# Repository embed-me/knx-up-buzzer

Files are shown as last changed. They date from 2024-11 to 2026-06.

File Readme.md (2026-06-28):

# 🎵 KNX UP-Buzzer Project



The **UP-Buzzer** is a custom KNX-compatible buzzer project designed to fill the gap in the market for simple and functional KNX buzzers. By combining existing open-source hardware with custom components, this project ensures flexibility, ease of use, and extensibility.

## 🚀 Overview

This project integrates:
- 🖨️ Custom PCB
- 🛠️ Firmware
- 🏠 3D-printable housing
- 🧰 Software configuration file

Together, these components enable a KNX-compatible buzzer with additional (untested!) features.

## PCB

The PCB combines available KNX hardware with custom components for the buzzer functionality. Below is an overview of the key parts:

### **BCU (Bus Coupling Unit)**

The BCU interfaces with the KNX bus using the **NCN5130** chip. This project uses the open-source [NanoBCU](https://github.com/OpenKNX/OpenKNX/wiki/NanoBCU) to simplify development.

> 🛒 You can purchase the NanoBCU hardware here: [NanoBCU Standard](https://muster.ing-dom.de/Busankoppler/NanoBCU-Standard.html).

### **MCU (Microcontroller Unit)**

The microcontroller is based on the **RP2040**, an open-source solution provided by [OpenKNX-UP1](https://github.com/OpenKNX/OpenKNX/wiki/OpenKNX-UP1).
To program the board, use the [UP1-Progger](https://github.com/OpenKNX/OpenKNX/wiki/UP1-Progger).

> 🛒 Both the UP1 controller and programmer are available [here](https://muster.ing-dom.de/OpenKNX-UP1/OpenKNX-UP1-Controller2040.html).

### **Buzzer, Proximity Sensor, and Binary Inputs**

The schematic includes:
- A **buzzer** for alert functionality.
- Support for a **proximity sensor** for advanced triggering.
- **Binary inputs** for potential-free connections.

These additional features are currently untested but are included for enthusiasts to explore.

> 🛒 I ordered mine at [JLCPCB](https://jlcpcb.com/).

📂 For schematics, PCB layouts, and Gerber files, see the [hardware documentation](hardware/Readme.md).

## Housing

The housing is designed to fit into a standard flush-mounted box and can be 3D-printed.

📂 Get the 3D model and instructions in the [housing documentation](housing/Readme.md).

## Firmware

The custom firmware is built to be:
- 🔧 Extensible
- ✅ Understandable
- 🔓 Easy to modify

⚠️ Note: Unit tests are not included (yet!), but the code is designed with maintainability in mind.

📂 For build instructions, see the [firmware documentation](firmware/Readme.md).

## 🛠️ Software

The project includes a KNX **product database** for configuration within **ETS**. This allows you to set up and use the device as seamlessly as you would with any commercial product.

📂 Learn how to modify and deploy the product database in the [software documentation](software/Readme.md).

## 📜 License

This project is licensed under **MIT License**. For details, check out the [LICENSE file](LICENSE).

---

Enjoy building and using the **UP-Buzzer**! 🎉

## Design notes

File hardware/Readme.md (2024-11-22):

# Hardware

PCB to add capabilities for buzzing, proximity sensor and binary inputs. The project is based on Altium Designer and can be found in [project](project/)

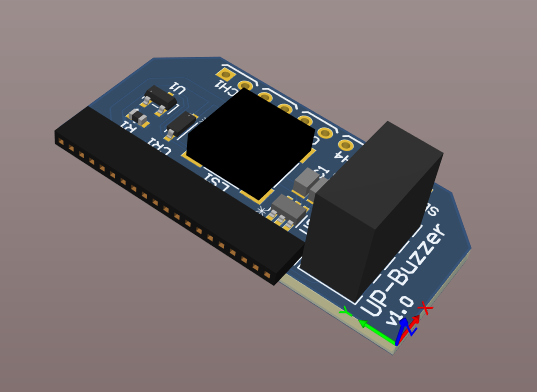
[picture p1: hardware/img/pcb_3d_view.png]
3d


## 3D rendering

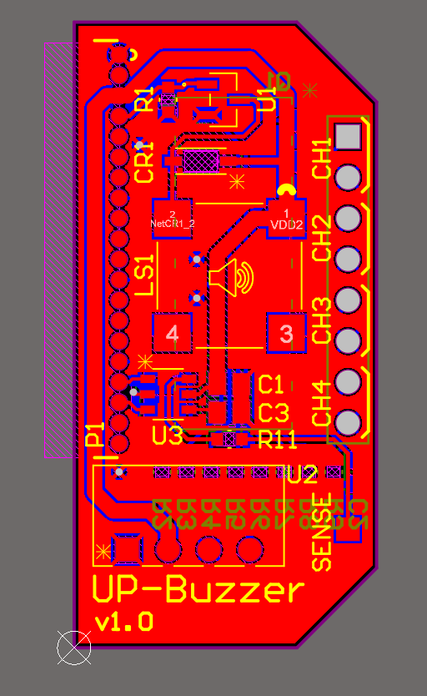
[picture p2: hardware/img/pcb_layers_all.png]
layers

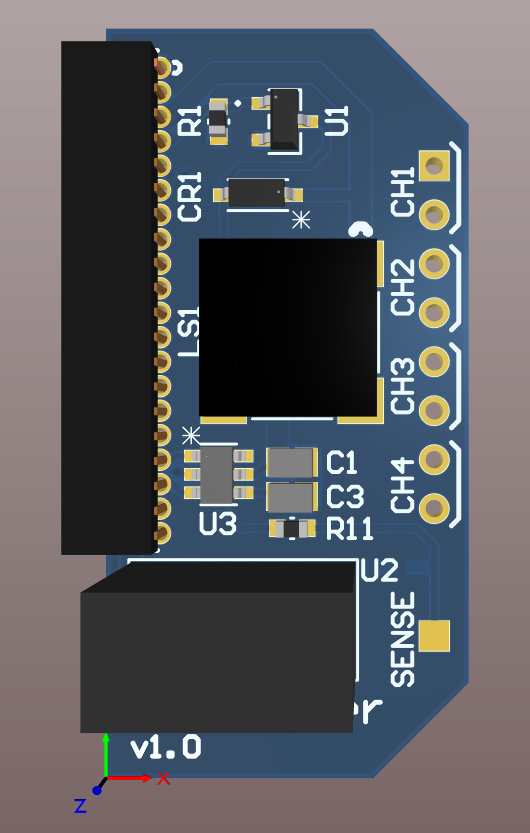
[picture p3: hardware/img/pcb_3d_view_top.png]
top


## Production Package

In case you just want to order the PCB, feel free to use the files in the [production package](production_package/).

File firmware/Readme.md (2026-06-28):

# 🛠️ UP Buzzer - Firmware

To ensure the application functions correctly, the product database must be imported into **ETS**, the physical address must be set, and the application must be written to the device.

## Setup

```bash
pip install platformio
```

## Build

```bash
pio run -e release
```

## Unit Tests

```bash
pio test -e test
```

## Static Code Analysis

```bash
sudo apt-get install -y cppcheck
pio check -e check
```

## Flashing

The **RP2040 UF2 ROM bootloader** is the recommended method for flashing the firmware due to its simplicity.

### Flashing Steps

1. Connect the board to your computer using the debugger port.
2. Press and hold the `Bootsel` button while pressing and releasing the `Reset` button.
3. A new USB drive will appear on your computer.
4. Drag and drop the file `.pio/build/release/firmware.uf2` onto the USB drive.

## Debugging

The easiest way to debug the firmware without using a dedicated debugger is through **printf debugging** via a serial console. 

### Enabling Serial Debugging

By default, logging output is disabled. To enable it:
1. Modify the logger initialization in `main.cpp` by setting the desired log level and ensuring logging starts when the serial connection is established:
   ```cpp
   logger->init(drivers::logger::LOGLEVEL::LOGLEVEL_TRACE, true);
   ```
2. Connect the debugger board to your computer.
3. Open PlatformIO's Serial Monitor.
4. Set the serial settings to 115200 baud rate, 1 stop bit, 8 data bits, no parity.
5. Observe the logging output for debugging information, including early boot messages.

## Extending functionality

The software configurations are organized into **modes**, which can be found in the [modes](src/drivers/knx/data/modes/) directory. During initialization, these modes are populated by reading the memory configuration from flash and are referenced within `MelodyConfig.hpp` via the `KnxConfig.hpp` file.

Once the configuration is loaded, it is applied to the corresponding **behavior**—defined in the [behaviours](src/application/behaviour/) directory—which determines the specific behavior for each mode. The correct behavior is automatically selected by the controller based on the user’s configuration in **ETS**.

To implement a new behavior, it must be added to the existing set of behaviors. It’s recommended to start by copying and modifying an existing mode to create your new behavior.

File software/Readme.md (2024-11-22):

# 🛠️ Software

The UP-Buzzer project integrates seamlessly with **ETS**, primarily tested with **ETS 6.6**. However, the project can be adapted to work with older ETS versions if required.

## Usage

If you do not want to modify the product database and the ETS version matches, it is recommended to simply load the [existing product database](productdatabase/) into ETS.
Once loaded it can be used as you would use any other vendor product.

The melody definitions are based on [RTTTL](https://en.wikipedia.org/wiki/Ring_Tone_Text_Transfer_Language).

Currently, there are up to 8 melodies available, and each can be configured with one of three modes, as described below.

**Note**: Currently, no priority system is implemented, meaning that one melody can interrupt another while it's playing. However, adding a priority strategy is simple and can be done by extending the application.

---

### Trigger

This is the simplest mode. When a trigger telegram with a value of `1` is received, the melody will play once. If the trigger telegram has a value of `0`, it will be ignored, and no action will be taken.

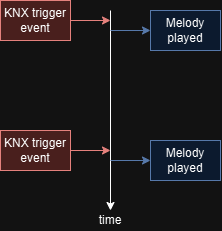
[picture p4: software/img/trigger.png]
Trigger Diagram


**Configuration**

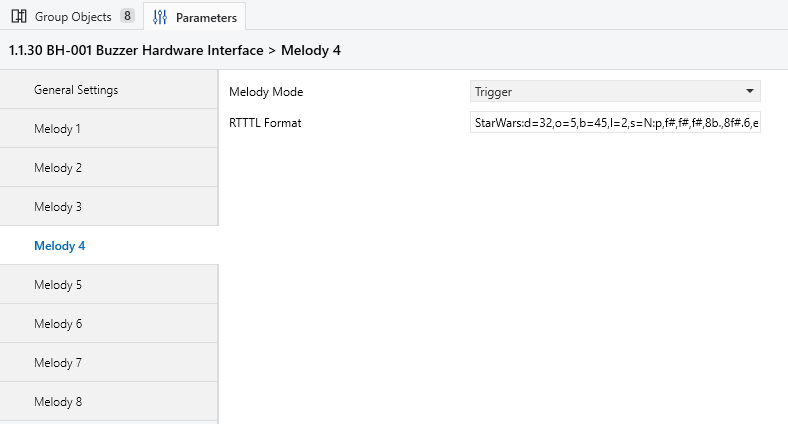
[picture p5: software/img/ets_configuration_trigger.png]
Trigger


---

### Switch

In this mode, when the Group Object receives a "start" command, the melody will play continuously. The melody will keep playing until a "stop" command is received, at which point it will stop.

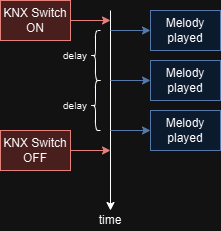
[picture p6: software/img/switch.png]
Switch Diagram


**Configuration**

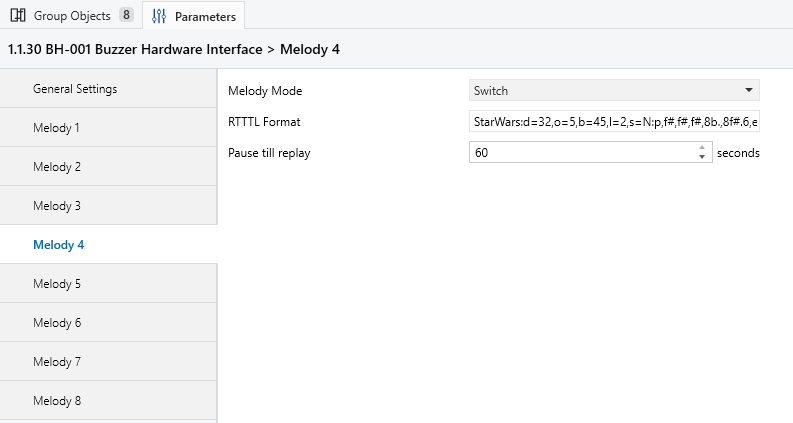
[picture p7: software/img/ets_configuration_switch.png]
Switch


---

### Venting Monitor

This mode allows you to set an upper and lower temperature threshold. The venting monitor is **disabled** when the temperature is within this range, helping to avoid unnecessary alerts.

This feature is particularly useful in scenarios like extreme summer heat or winter conditions when ventilation may not be exceeded. 

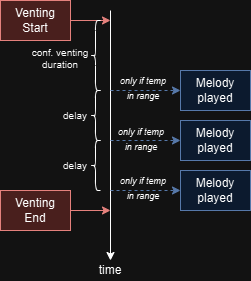
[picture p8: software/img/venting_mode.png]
Venting Monitor Diagram


**Configuration Requirements**:
- Connect the external temperature sensor Group Object.
- Connect the window/door contact sensor Group Object.

Once the window is opened, the ventilation timer starts. If the window remains open, the ventilation timer will restart automatically once the timeout is reached. This process ensures that even if the outdoor temperature drops outside the defined range at a later point in time, the alert will still trigger. Until the window is closed or the temperature thresholds are back in range, the melody will be played.

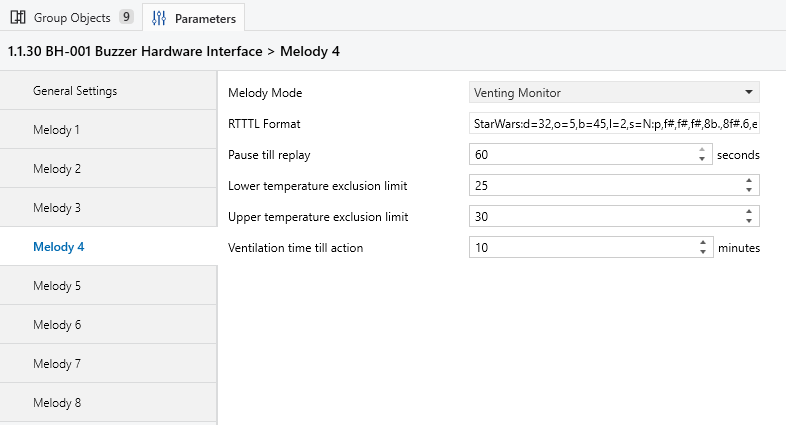
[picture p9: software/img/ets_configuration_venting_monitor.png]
Venting Monitor


## Tools

To create the KNX product database and provide full flexibility, this project uses:

- **[Kaenx-Creator](https://github.com/OpenKNX/Kaenx-Creator)**: A versatile tool for generating KNX product databases.

### Recommended Version

Kaenx-Creator is under active development, and updates can sometimes introduce breaking changes. For this project, it is recommended to use **[v1.8.4](https://github.com/OpenKNX/Kaenx-Creator/tree/v1.8.4)** to ensure compatibility.

- **Binary Download**: [Kaenx Creator v1.8.4](https://github.com/OpenKNX/Kaenx-Creator/releases/download/v1.8.4/Kaenx.Creator.Binaries.zip)
- **MD5 Hash**: `9aeb971f7844eeafb54341031f3e4ef8`

## Generation

To modify or recreate the product database:

1. Open the file `up-buzzer.ae-manu`.
2. Make any necessary changes and increase the version number.
3. Re-deploy the database.

The generated outputs include:

- **`knxprod.h`**: Move this file to [firmware/src/drivers/knx/data/](firmware/src/drivers/knx/data/).

### Note

During re-deployment, the program may become temporarily unresponsive. Allow it some time, as it will eventually complete successfully.

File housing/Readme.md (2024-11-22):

# 🏠 Housing

The housing for the UP-Buzzer is designed to be robust and compact, making it suitable for standard installations.

## Overview

The housing is designed to fit the necessary PCBs securely. Below is an image of the PCB arrangement:

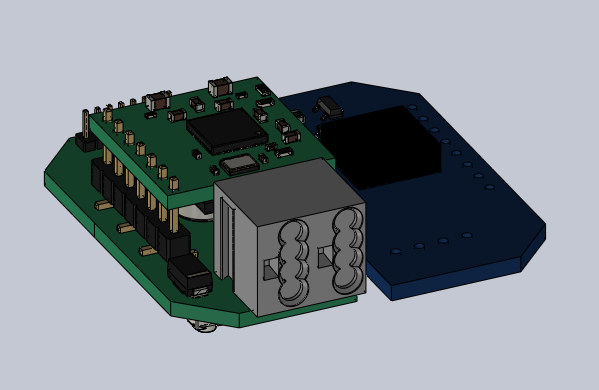
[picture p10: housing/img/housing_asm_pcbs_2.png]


## Model

The housing consists of two parts:
- **Top Shell**
- **Main Housing**

You can find the 3D model files in the [parts](parts/) directory. The assembly combining all PCBs is available in the [assembly](assembly/) directory.

Here’s a rendering of the 3D model with a transparent top shell:

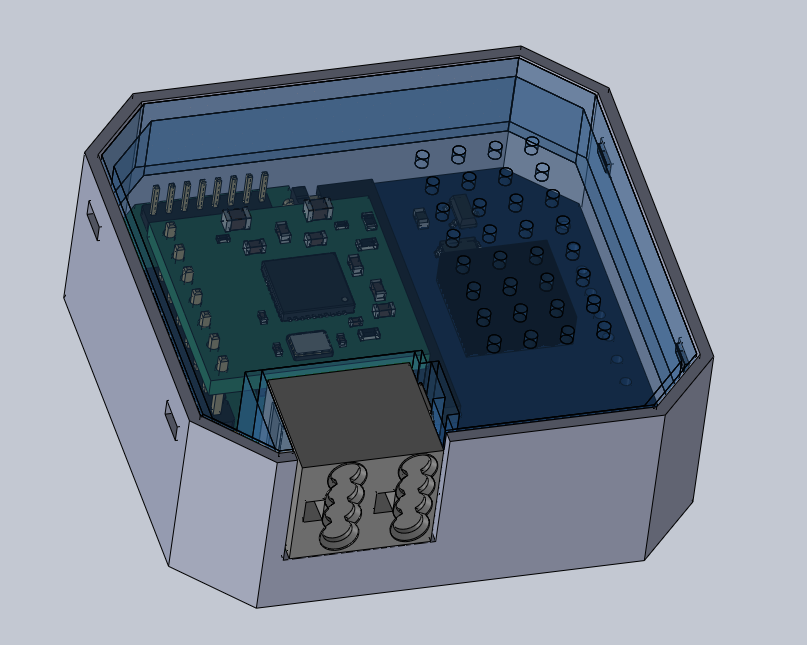
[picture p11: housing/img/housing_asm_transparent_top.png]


## Exported STL Files for Printing

If you’d like to print the housing as-is, the ready-to-use STL files are available in the [print_package](print_package/) directory.

## Result

Below is the final printed result:

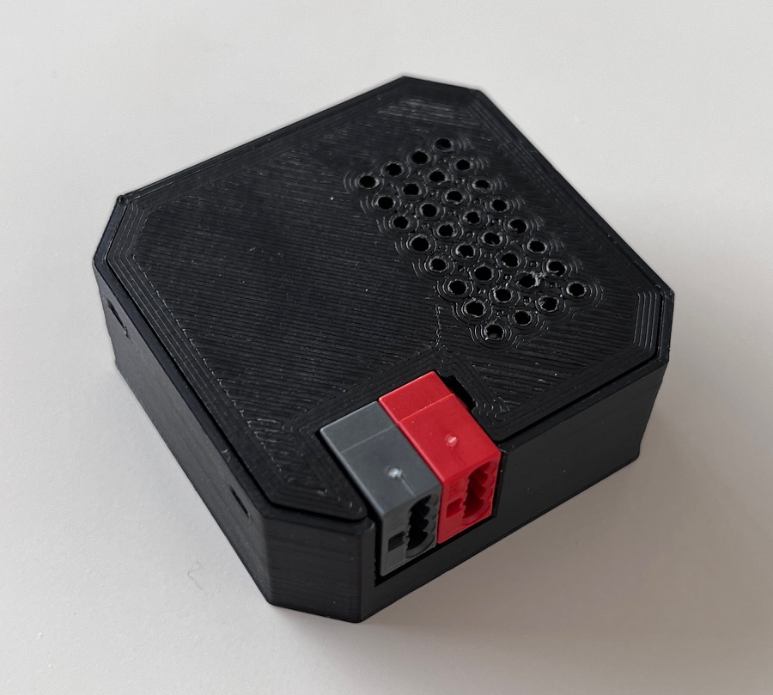
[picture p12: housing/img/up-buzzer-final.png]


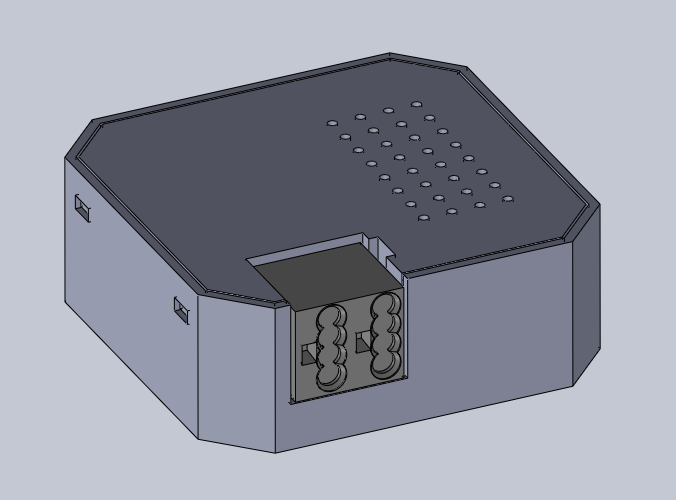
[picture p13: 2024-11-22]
housing/img/housing_asm_enclosed_top.png

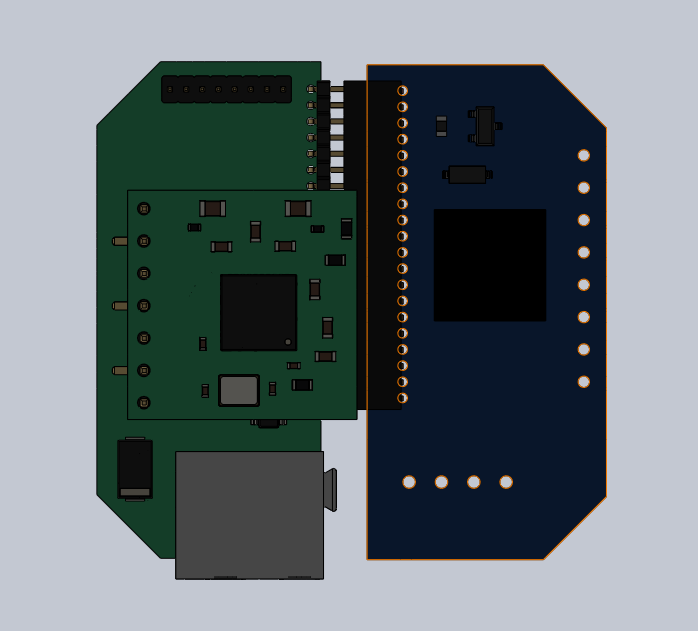
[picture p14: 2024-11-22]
housing/img/housing_asm_pcbs.png

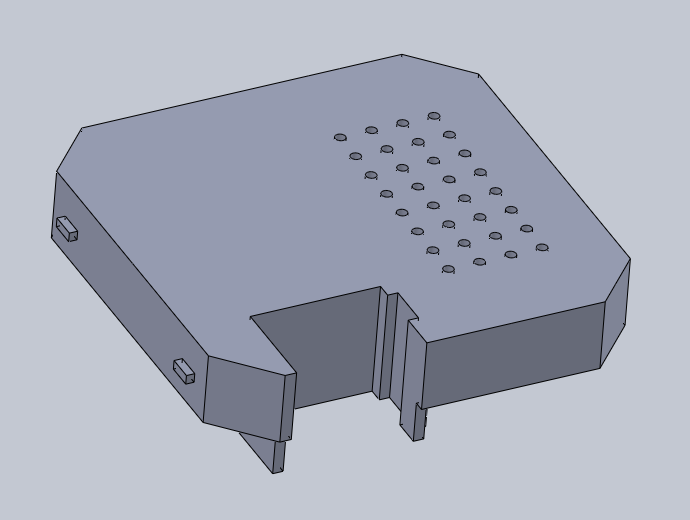
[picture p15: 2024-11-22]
housing/img/housing_top.png

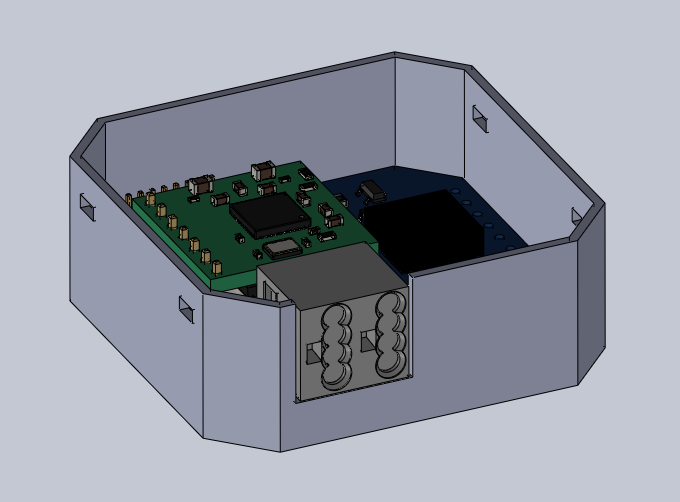
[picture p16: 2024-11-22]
housing/img/housing_asm_removed_top.png

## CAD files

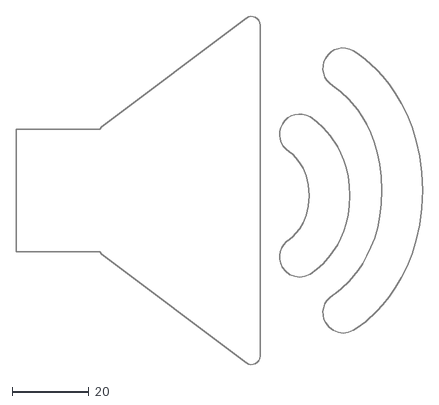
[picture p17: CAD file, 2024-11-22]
hardware/Logo/audio-buzzer.dxf
105.8 x 90.7

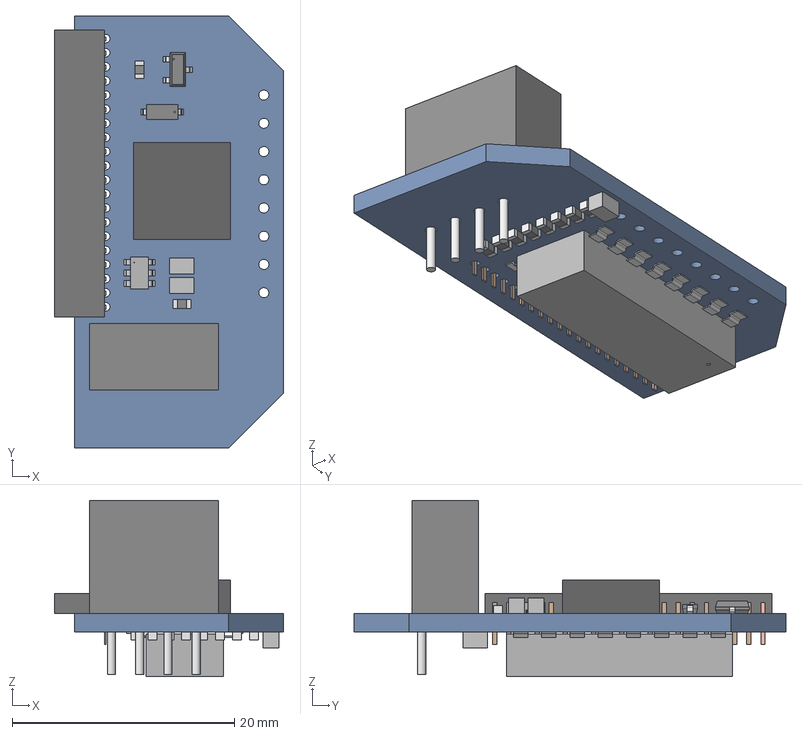
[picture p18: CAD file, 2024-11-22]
hardware/project/UP-Buzzer-PCB.step
20.6 x 38.9 x 15.8 mm
Extruded x 4
pinheader_20pin_127mm_pitch
SOD123_DIO

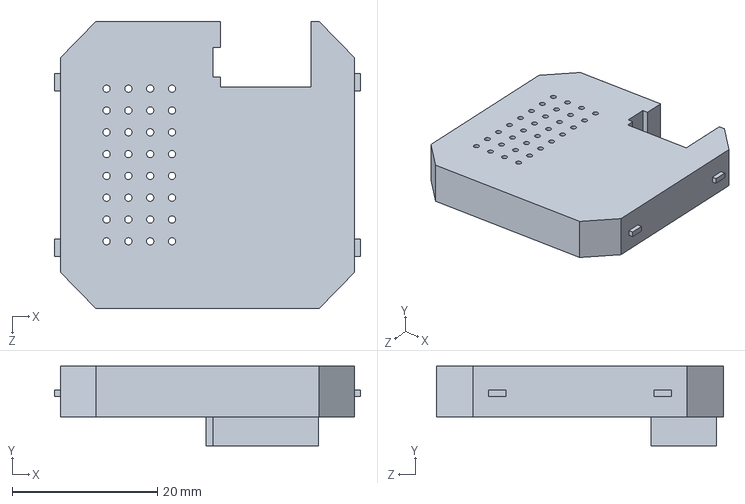
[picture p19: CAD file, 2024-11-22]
housing/parts/UP-Buzzer-housing-upper.SLDPRT
42.1 x 11.0 x 39.5 mm

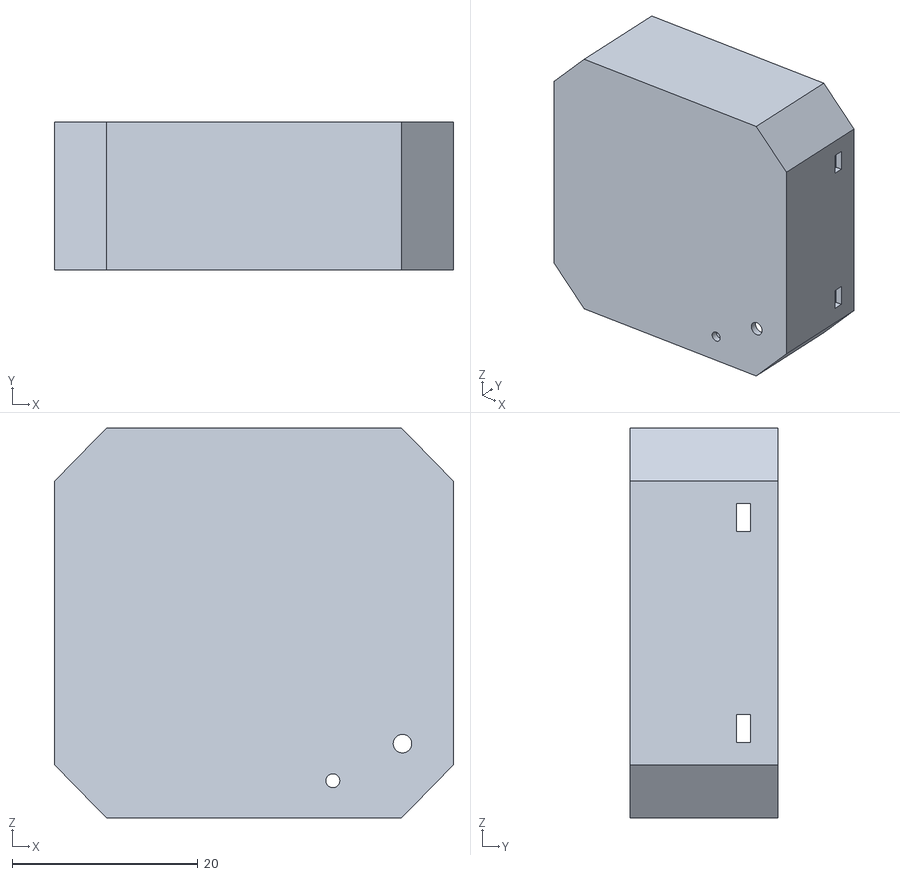
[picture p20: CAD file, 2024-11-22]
housing/print_package/UP-Buzzer-housing.STL
43.0 x 16.0 x 42.0

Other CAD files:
housing/parts/UP-Buzzer-housing.SLDPRT
housing/print_package/UP-Buzzer-housing-upper.STL

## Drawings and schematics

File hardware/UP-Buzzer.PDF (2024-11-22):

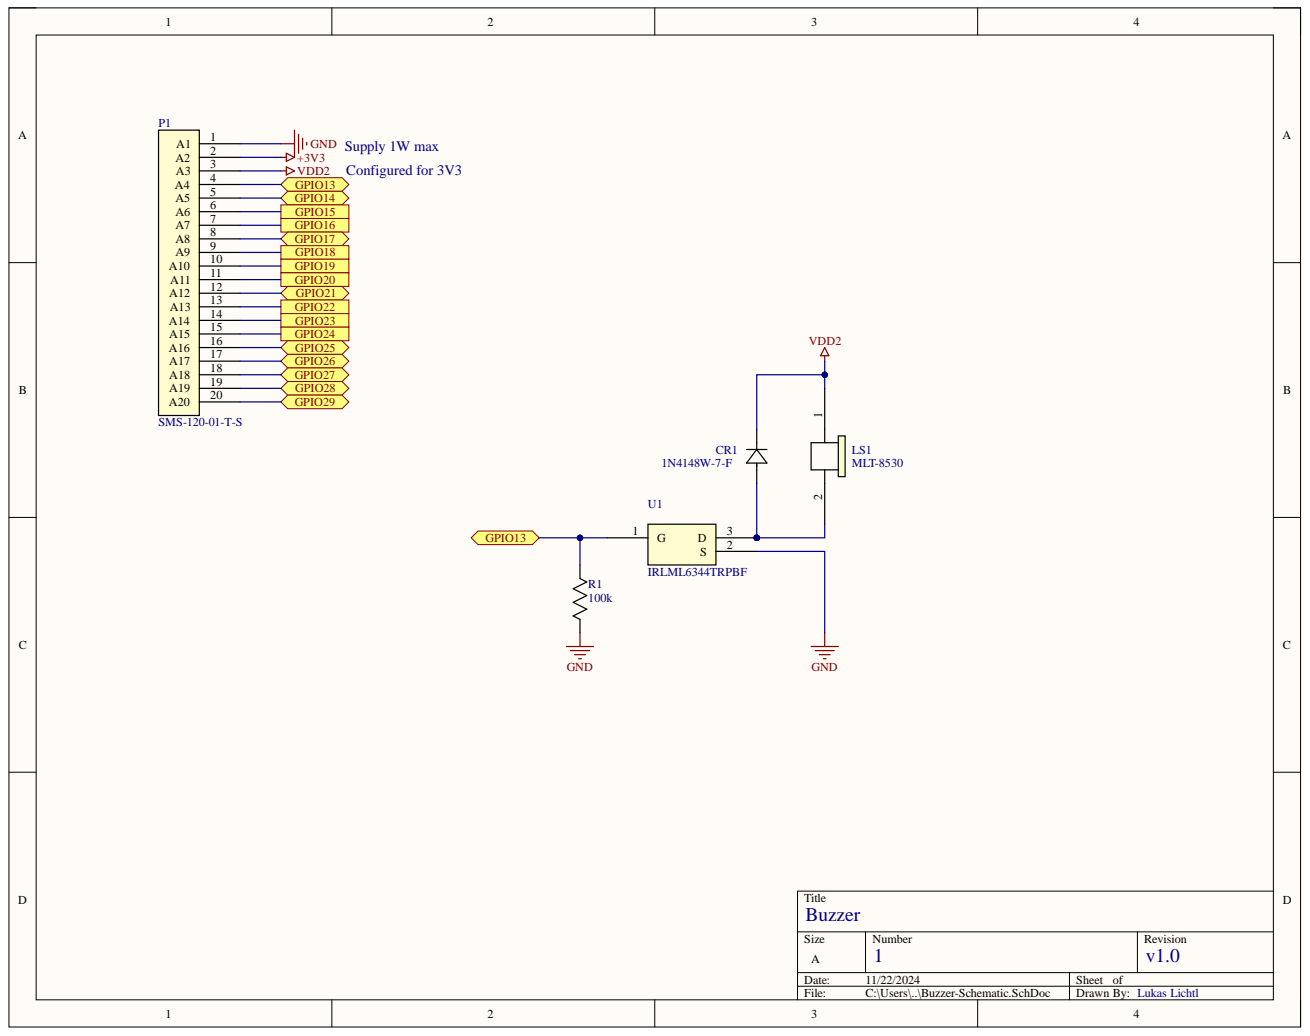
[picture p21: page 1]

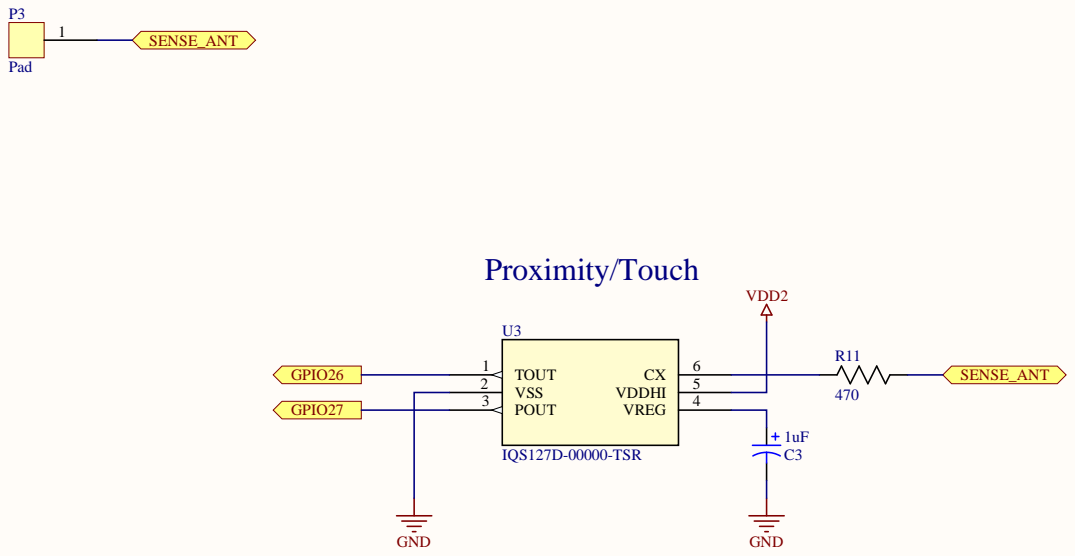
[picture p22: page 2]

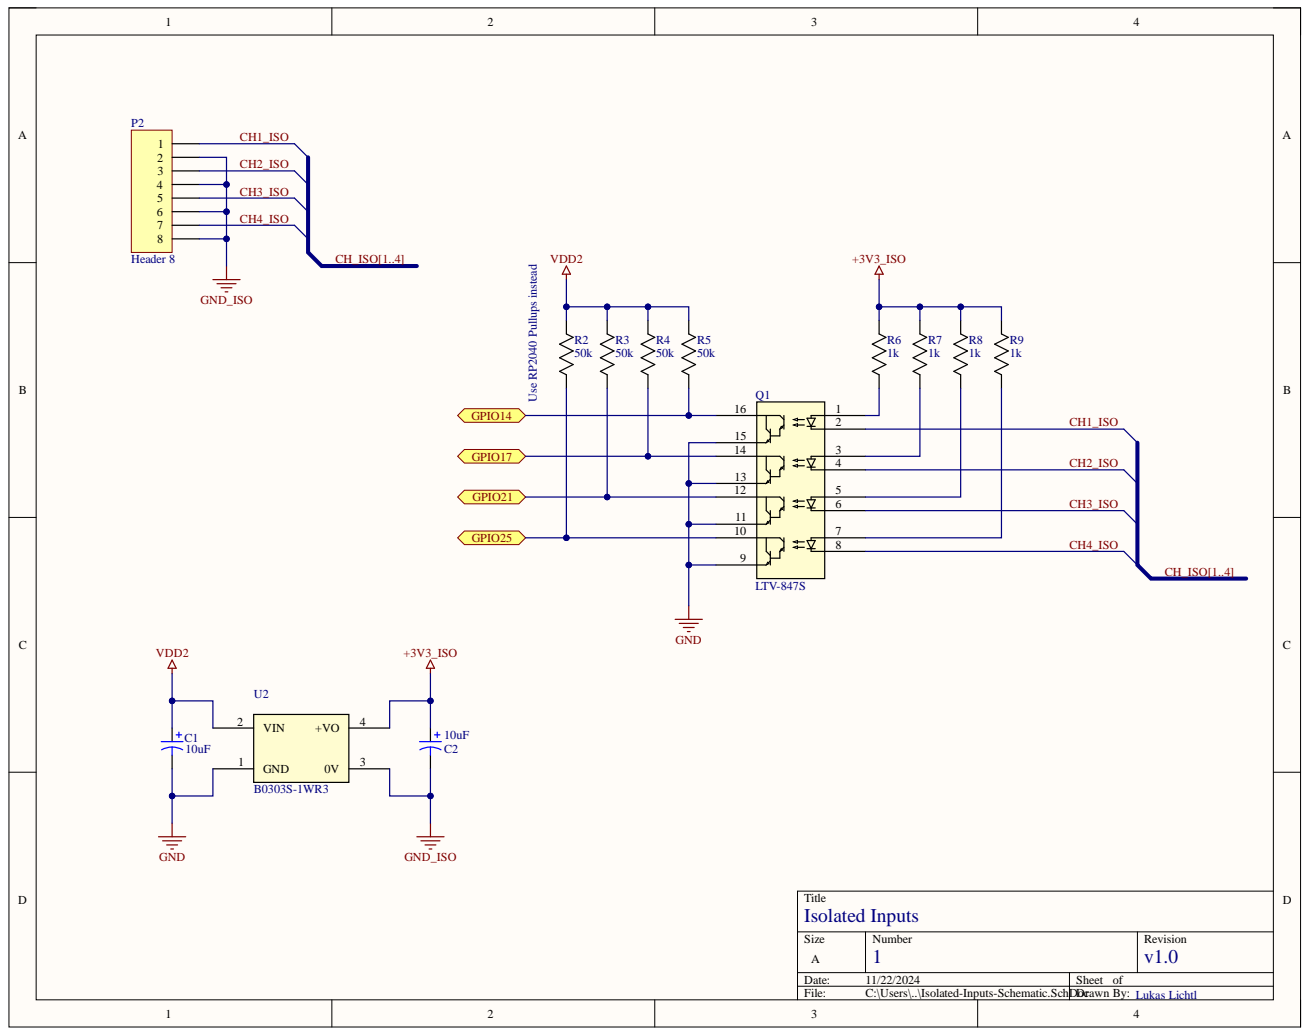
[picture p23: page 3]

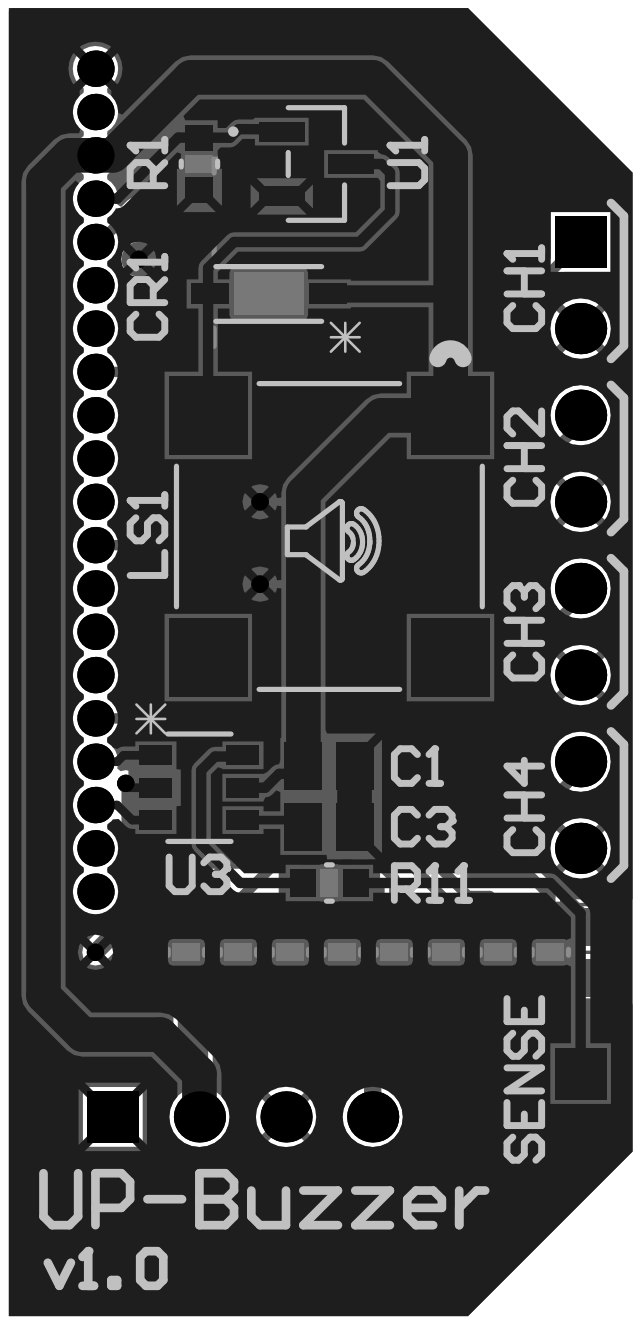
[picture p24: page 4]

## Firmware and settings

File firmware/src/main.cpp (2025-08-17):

#include <memory>
#include <list>

#include "drivers/ArduinoDriverFactory.hpp"

#include "drivers/logger/Logger.hpp"
#include "drivers/logger/ILogger.hpp"

#include "drivers/gpio/IGpioDriver.hpp"

#include "drivers/knx/IKnxDriver.hpp"
#include "drivers/knx/data/KnxConfig.hpp"

#include "drivers/buzzer/IBuzzerDriver.hpp"

#include "drivers/timer/ITimer.hpp"

#include "drivers/watchdog/IWatchdogDriver.hpp"

#include "utils/scheduler/Scheduler.hpp"
#include "utils/scheduler/strategy/ISchedulerStrategy.hpp"
#include "utils/scheduler/strategy/simple/SimpleScheduler.hpp"

#include "src/application/behaviour/IBehaviour.hpp"
#include "src/application/behaviour/BehaviourFactory.hpp"

#include "src/application/priority/IPriority.hpp"
#include "src/application/priority/no_priority/NoPriority.hpp"

#include "application/MelodyController.hpp"

/* GPIOs */
struct drivers::gpio::GpioConfig knxProgButton = {
    .pin = 7,
    .sensitivity = drivers::gpio::GPIO_SENSITIVITY::INTERRUPT_CHANGE,
    .direction = drivers::gpio::GPIO_DIRECTION::DIRECTION_INPUT,
    .pull = drivers::gpio::GPIO_PULL::PULL_HIGH
};

struct drivers::gpio::GpioConfig knxProgLed = {
    .pin = 6,
    .sensitivity = drivers::gpio::GPIO_SENSITIVITY::ACTIVE_HIGH,
    .direction = drivers::gpio::GPIO_DIRECTION::DIRECTION_OUTPUT,
    .pull = drivers::gpio::GPIO_PULL::PULL_NONE
};

struct drivers::gpio::GpioConfig buzzerPin = {
    .pin = 13,
    .sensitivity = drivers::gpio::GPIO_SENSITIVITY::ACTIVE_HIGH,
    .direction = drivers::gpio::GPIO_DIRECTION::DIRECTION_OUTPUT,
    .pull = drivers::gpio::GPIO_PULL::PULL_NONE
};

/* Drivers */
std::shared_ptr<drivers::IDriverFactory> driverFactory = std::make_shared<drivers::ArduinoDriverFactory>();
#ifdef KNX_UP_BUZZER_DISABLE_LOGGING
    std::shared_ptr<drivers::logger::ILogger> logger = nullptr;
#else
    std::shared_ptr<drivers::logger::ILogger> logger = driverFactory->getLoggerDriver();
#endif
std::shared_ptr<drivers::gpio::IGpioDriver> gpio = driverFactory->getGpioDriver();
std::shared_ptr<drivers::audio::IBuzzerDriver> buzzer = driverFactory->getBuzzerDriver(buzzerPin);
std::shared_ptr<drivers::knx::IKnxDriver> knx = driverFactory->getKnxDriver();
std::shared_ptr<drivers::watchdog::IWatchdogDriver> watchdog = driverFactory->getWatchdogDriver();

/* Utilities */
std::shared_ptr<utils::ISchedulerStrategy> schedulerStrategy = std::make_shared<utils::SimpleScheduler>();
std::shared_ptr<utils::Scheduler> scheduler = std::make_shared<utils::Scheduler>(schedulerStrategy);

/* Applications */
std::shared_ptr<application::priority::IPriority> priorityStrategy = std::make_shared<application::priority::NoPriority>();
std::shared_ptr<application::behaviour::BehaviourFactory> behaviourFactory = std::make_shared<application::behaviour::BehaviourFactory>(knx, driverFactory, buzzer);

std::shared_ptr<application::MelodyController> controller = std::make_shared<application::MelodyController>(priorityStrategy, behaviourFactory);

#define WDT_TIMEOUT_MS 8000
#define PROG_BTN_PRESS_MIN_MILLIS 50
#define PROG_BTN_PRESS_MAX_MILLIS 500

void buttonPressHandler(void *arg) 
{
    static uint32_t lastEvent = 0;
    static uint32_t lastPressed = 0;

    uint32_t diff = millis() - lastEvent;

    if (diff >= PROG_BTN_PRESS_MIN_MILLIS && diff <= PROG_BTN_PRESS_MAX_MILLIS)
    {
        if (millis() - lastPressed > 200)
        {
            knx->toggleProgMode();
            lastPressed = millis();
        }
    }

    lastEvent = millis();
}

void buttonInterrupt()
{
    utils::Scheduler::schedule(buttonPressHandler);
}

/* Core 0 */
void setup() {
    //drivers::logger::Logger::setLogger(logger);
    //logger->init(drivers::logger::LOGLEVEL::LOGLEVEL_TRACE, true);

    watchdog->enable(WDT_TIMEOUT_MS);

    gpio->setConfig(knxProgLed);
    gpio->setConfig(knxProgButton);
    gpio->setConfig(buzzerPin);
    gpio->setupInterruptHandler(knxProgButton, buttonInterrupt);

    bool stackConfigured = knx->init();
    knx->setProgmodeChangeCallback([](bool val) {
        gpio->writeValue(knxProgLed, val);
    });

    std::string version = knx->getApplicationVersion();
    logInfo("Application Version: " + version);

    drivers::knx::KnxConfig cfg = knx->getKnxConfig();
    std::list<drivers::knx::MelodyConfig> melodyCfgs = cfg.getMelodyConfigs();
  
    if (stackConfigured) {
        controller->init(melodyCfgs);
    }
}

void loop() {
    watchdog->feed();
    scheduler->process();
}


/* Core 1 */
void setup1() {
}

void loop1() {
}

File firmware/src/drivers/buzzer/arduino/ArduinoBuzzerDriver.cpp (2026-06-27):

#include "ArduinoBuzzerDriver.hpp"

#include <Arduino.h>
#include <PlayRtttl.hpp>
#include "src/utils/scheduler/Scheduler.hpp"
#include "src/drivers/logger/Logger.hpp"

using namespace drivers::audio;
using namespace drivers::logger;

ArduinoBuzzerDriver::ArduinoBuzzerDriver(const drivers::gpio::GpioConfig &gpio,
                                         std::shared_ptr<drivers::ITimerDriverFactory> timerFactory) :
    gpio(gpio),
    timer(timerFactory->getTimer())
{
    timer->setupInterruptHandler(timerInterrupt, this);
}

void ArduinoBuzzerDriver::play(const drivers::knx::Melody &melody)
{
    char melodyName[32];
    getRtttlName(melody.rtttl, melodyName, sizeof(melodyName)-1);
    logInfo("Playing Melody %s",  melodyName);
    
    stopScheduled = false;
    startPlayRtttl(gpio.pin, melody.rtttl, NULL);
    timer->start(100, drivers::timer::TimerMode::RECURRING);

    notifyObservers(BuzzerStatus::STATUS_ON);
}

void ArduinoBuzzerDriver::registerBuzzerChangeObserver(IBuzzerChangeObserver *observer)
{
    this->observer = observer;
}

bool ArduinoBuzzerDriver::isPlaying()
{
    return isPlayRtttlRunning();
}

void ArduinoBuzzerDriver::stop()
{
    logInfo("Stopping Melody");

    stopPlayRtttl();
    timer->stop();
    stopScheduled = false;
    
    notifyObservers(BuzzerStatus::STATUS_OFF);
}

void ArduinoBuzzerDriver::notifyObservers(enum BuzzerStatus status)
{
    if (observer) {
        observer->onBuzzerChange(status);
    }
}

void ArduinoBuzzerDriver::timerInterrupt(void *arg)
{
    ArduinoBuzzerDriver *instance = static_cast<ArduinoBuzzerDriver*>(arg);
    if (instance == nullptr) {
        return;
    }

    utils::Scheduler::schedule([instance](void*) {
        if (!instance) {
            return;
        }

        bool isStillPlaying = updatePlayRtttl();
        if (isStillPlaying) {
            return;
        }

        if (!instance->stopScheduled) {
            instance->stopScheduled = true;
            instance->stop();
        }
    });
}

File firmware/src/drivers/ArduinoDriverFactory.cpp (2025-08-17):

#include "ArduinoDriverFactory.hpp"

#include "timer/arduino/ArduinoTimer.hpp"
#include "gpio/arduino/ArduinoGpioDriver.hpp"
#include "buzzer/arduino/ArduinoBuzzerDriver.hpp"
#include "logger/arduino/ArduinoLogger.hpp"
#include "knx/arduino/ThelsingKnxDriver.hpp"
#include "watchdog/arduino/ArduinoWatchdogDriver.hpp"

#include "logger/Logger.hpp"

using namespace drivers;
using namespace drivers::logger;

ArduinoDriverFactory::ArduinoDriverFactory()
{
}

std::shared_ptr<timer::ITimer> ArduinoDriverFactory::getTimer()
{
    logTrace("creating new Timer");
    auto timer = std::make_shared<timer::ArduinoTimer>();
    return timer;
}

std::shared_ptr<gpio::IGpioDriver> ArduinoDriverFactory::getGpioDriver()
{
    logTrace("creating new Gpio Driver");
    auto gpio = std::make_shared<gpio::ArduinoGpioDriver>();
    return gpio;
}

std::shared_ptr<logger::ILogger> ArduinoDriverFactory::getLoggerDriver()
{
    auto logger = std::make_shared<logger::ArduinoLogger>();
    return logger;
}

std::shared_ptr<audio::IBuzzerDriver> ArduinoDriverFactory::getBuzzerDriver(const drivers::gpio::GpioConfig &gpio)
{
    logTrace("creating new Buzzer Driver");
    auto buzzer = std::make_shared<audio::ArduinoBuzzerDriver>(gpio, shared_from_this());
    return buzzer;
}

std::shared_ptr<knx::IKnxDriver> ArduinoDriverFactory::getKnxDriver()
{
    logTrace("creating new Knx Driver");
    auto knx = std::make_shared<knx::ThelsingKnxDriver>(shared_from_this());
    return knx;
}

std::shared_ptr<watchdog::IWatchdogDriver> ArduinoDriverFactory::getWatchdogDriver()
{
    logTrace("creating new Watchdog Driver");
    auto watchdog = std::make_shared<watchdog::ArduinoWatchdogDriver>();
    return watchdog;
}

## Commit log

2025-02-21 disable ArduinoLog library due to ve_end bug, static analysis improvements
    [ArduinoBuzzerDriver.cpp]
2025-08-17 improve buzzer timer scheduling to avoid usage in ISR context
    [ArduinoBuzzerDriver.cpp]
